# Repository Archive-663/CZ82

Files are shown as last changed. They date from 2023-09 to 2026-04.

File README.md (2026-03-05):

# Lot no. 008 | Grips, Holsters, and Speedloader for the CZ82

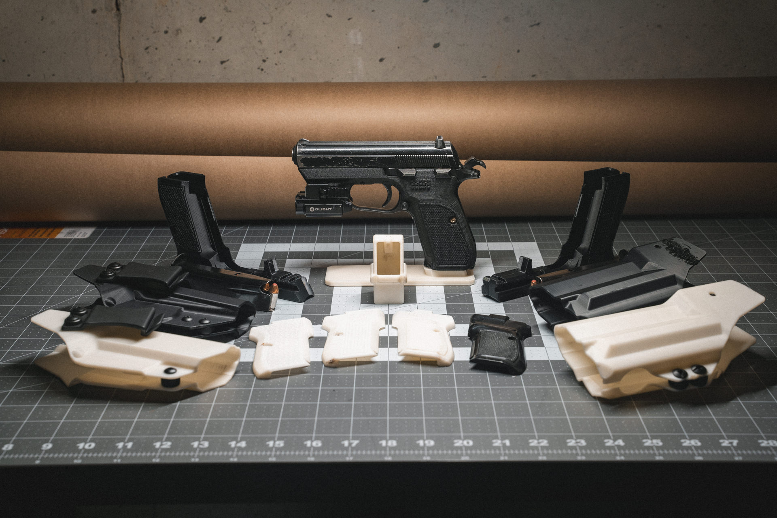
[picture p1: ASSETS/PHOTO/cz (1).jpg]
samplePhoto001


### In this repository:
- [CZ-82 Grips](https://github.com/Archive-663/CZ82/tree/main/Grips)
- [CZ-82 Holsters](https://github.com/Archive-663/CZ82/tree/main/Holsters)
- [CZ-82 +2 Magazine Extension](https://github.com/Archive-663/CZ82/tree/main/Magazine%20Base%20Plate)
- [CZ-82 Speedloader/unloader](https://github.com/Archive-663/CZ82/tree/main/Speedloader)
- [CZ-82 Reverse Engineered Frame & Magazine Assembly in STEP](https://github.com/Archive-663/CZ82/tree/main/baseCZ82_Body)
- [Small Collection of compact weapon lights](https://github.com/Archive-663/CZ82/tree/main/Lights)

### Background Story:
I wanted to carry my CZ-82 with a light, but there weren't any options for me to make this happen. Four years ago I started 3D printing and designing in CAD for photography related things. About two years ago I tried to design a NATO grip for the 82 but didn't like the accuracy of the design as well as the fit. Earlier this year I picked up a 3D scanner that allowed me to better design a fitted NATO grip by helping me reverse engineer the frame and slide. The included CZ82 Frame Assembly STEP file is my best approximation at what CZ designers were thinking back in the 80's. With time and tooling wear through batches there may be some inconsistencies in my file, but it's a good starting point to fit your own grips on your 82/83.

It was a frustratingly hard thing to wrap my head around. It took me about four start ups to finally start understanding how I should be thinking when reverse engineering a made product. There was a lot of guessing at what the 'designer intent' was when making measurements and curves. It was a good learning experience and I believe the finished file is a very good digital approximation of the CZ-82 frame.

### Help support Archive 663 with a dontation or monthly sub



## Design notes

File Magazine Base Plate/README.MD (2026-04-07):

# CZ-82 Plus 2 Magazine Extension

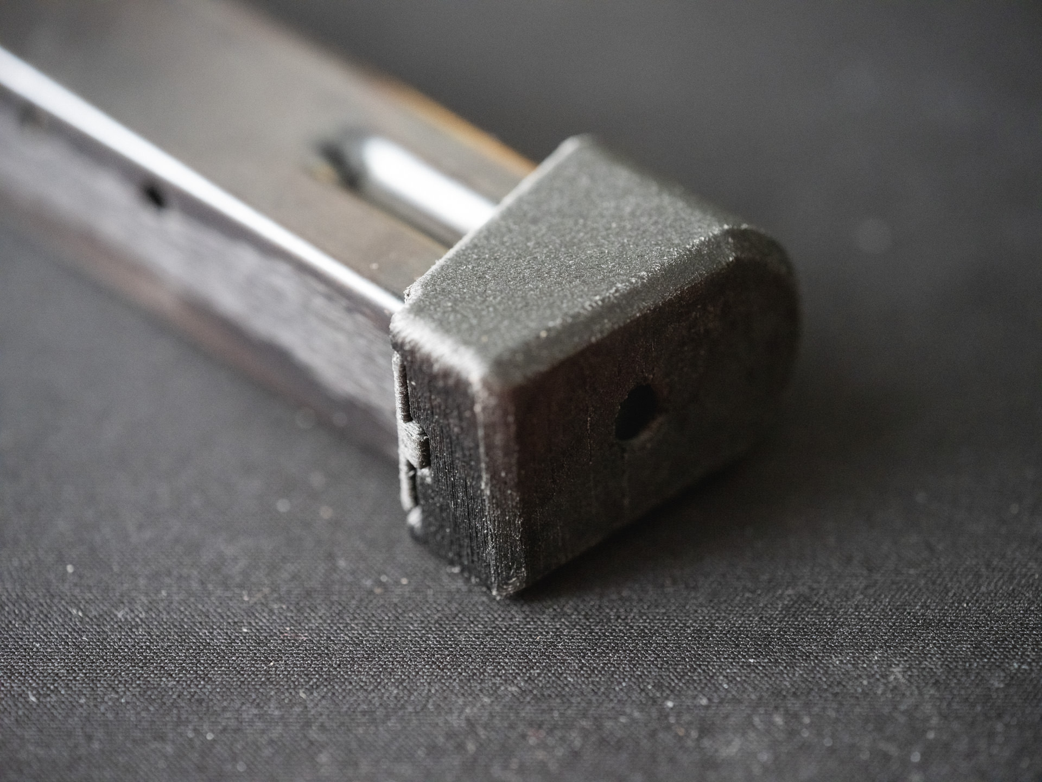
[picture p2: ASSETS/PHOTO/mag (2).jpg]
CZ-82 Plus 2 Magazine Extension 1

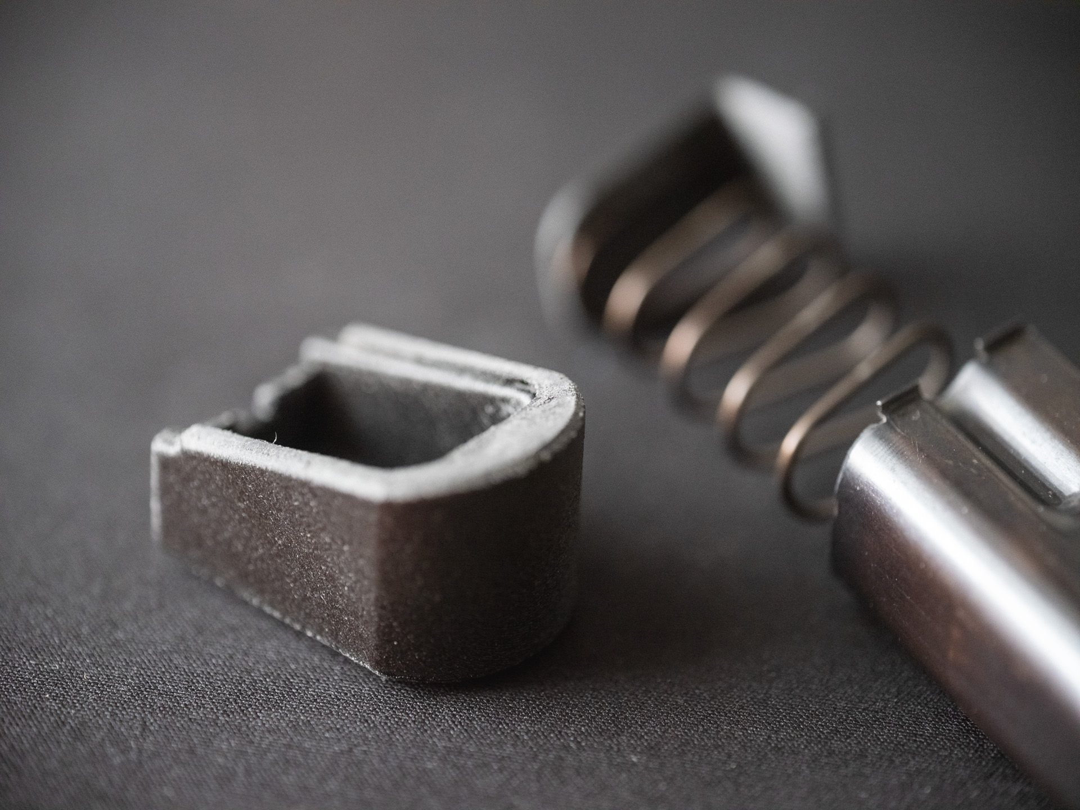
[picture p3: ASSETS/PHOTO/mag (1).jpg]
CZ-82 Plus 2 Magazine Extension 2


A working +2 round magazine extension.

### Features:
- +2 Magazine capacity
- Compatible with Type 1 (Round) and Type 2 (Square) Main Spring Plug

### What you'll need:
- A set of diamond micro files (0.25mm, 0.5mm, 0.75mm)
or 
- A clean sharp edge

### Assembly:
Remove the factory spring retention plate and slide the last spring loop into the printed spring retention plate. Compress the spring and spring retention plate. Slide the +2 magazine base plate on. Allow the spring to decompress, push down on the spring retention plate if it does not drop down.

You want to slide the +2 magazine base plate on without the spring and spring retention plate to ensure that the kerf allows the +2 base plate to slide on without too much issue. It's printed and designed tight to allow for the most material on the upper lip of the kerf.

### Printing suggestion:
- PA6-CF filament offers the best performance.
- If you have the round cylindrical (Type 1) Main Spring Plug print "..._springRetainer_+2.stl"
- If you have the square (Type 2) Main Spring Plug pring "..._springRetainerType2_+2.stl"

### Post Processing:
- Clean any stray filament.
- If possible run a .75mm file through the rim of the +2 magazine base plate to ready it for sliding onto the magazine.

### Help support Archive 663 with a dontation or monthly sub



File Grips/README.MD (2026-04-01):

# CZ-82 Grips

CZ-82 Speedloader
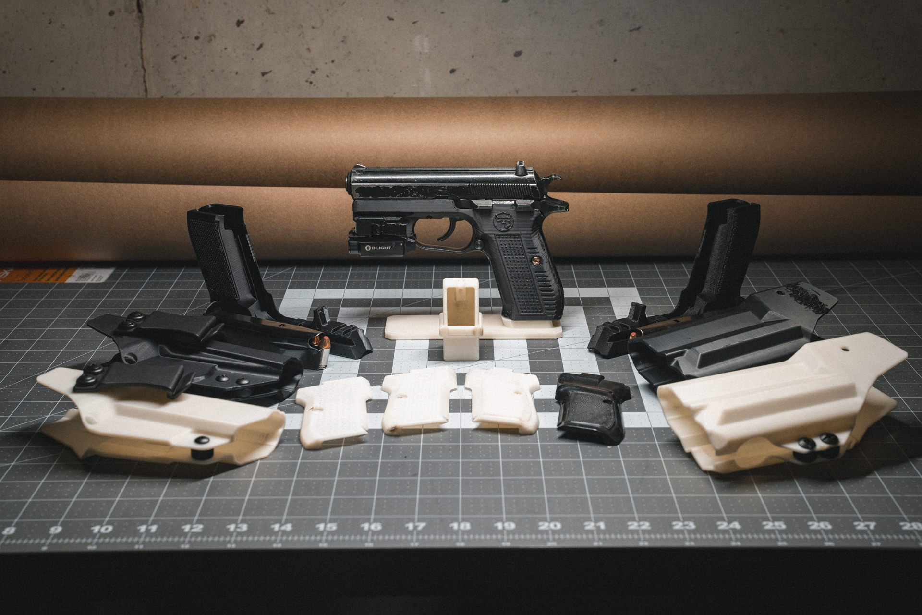
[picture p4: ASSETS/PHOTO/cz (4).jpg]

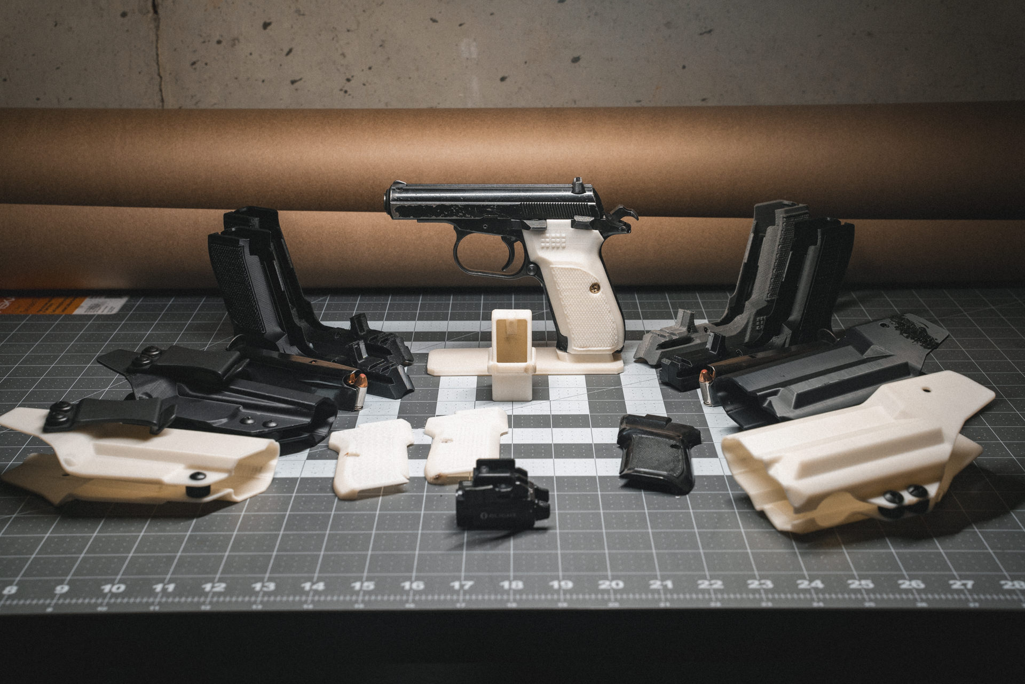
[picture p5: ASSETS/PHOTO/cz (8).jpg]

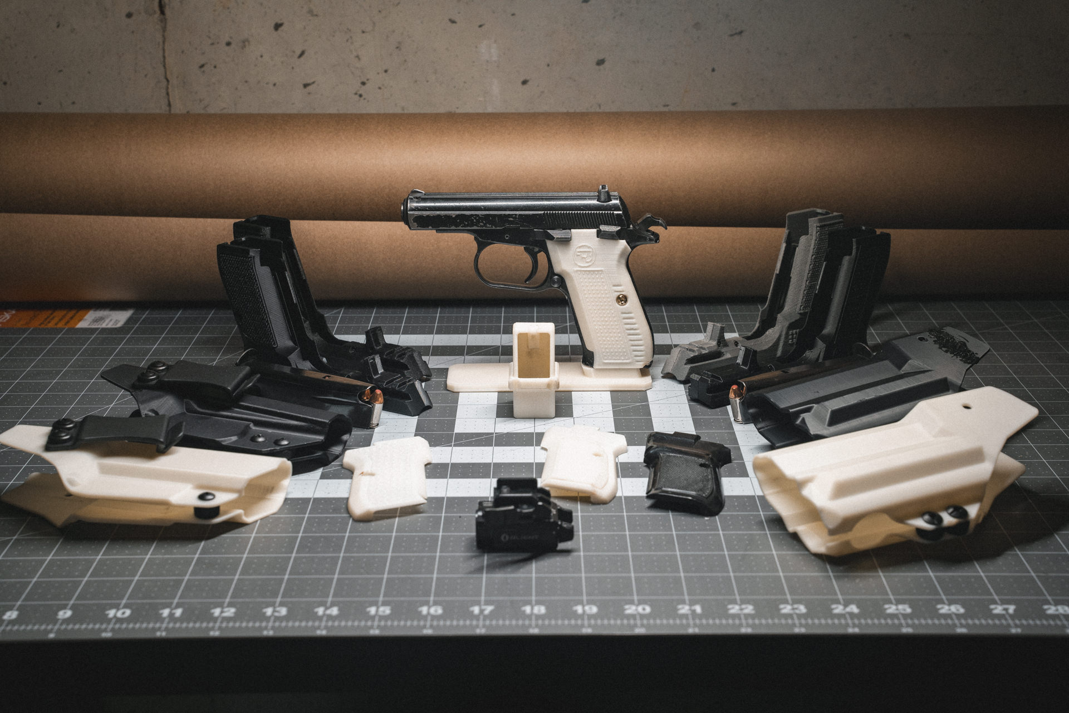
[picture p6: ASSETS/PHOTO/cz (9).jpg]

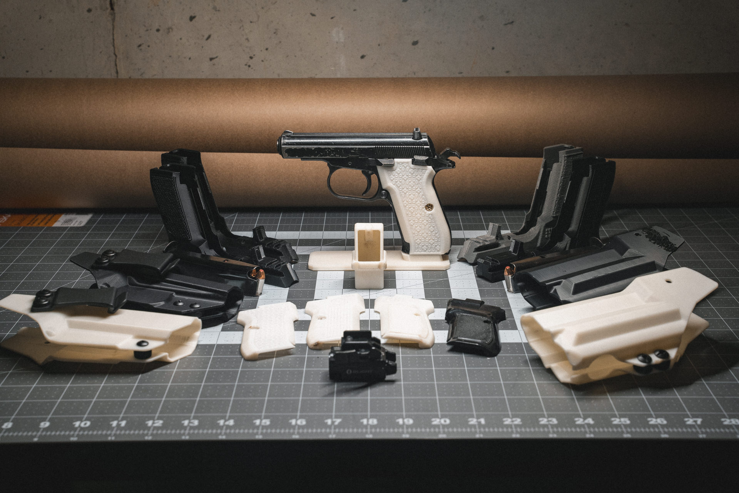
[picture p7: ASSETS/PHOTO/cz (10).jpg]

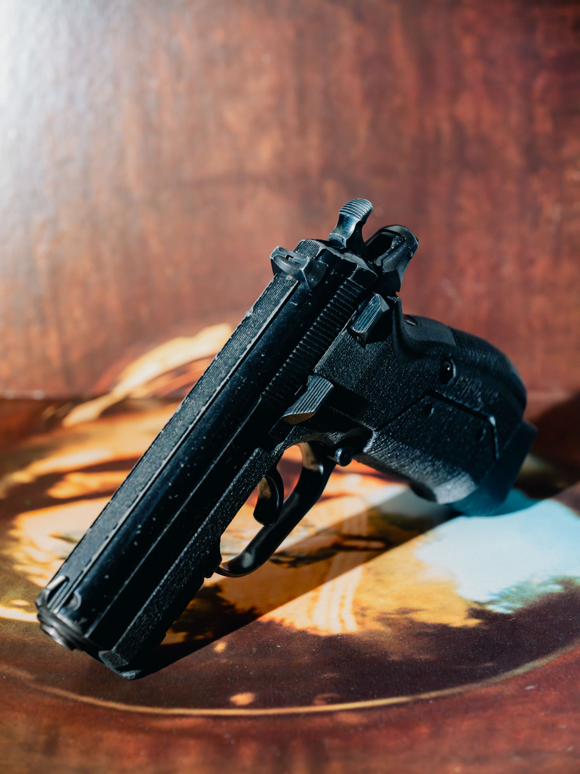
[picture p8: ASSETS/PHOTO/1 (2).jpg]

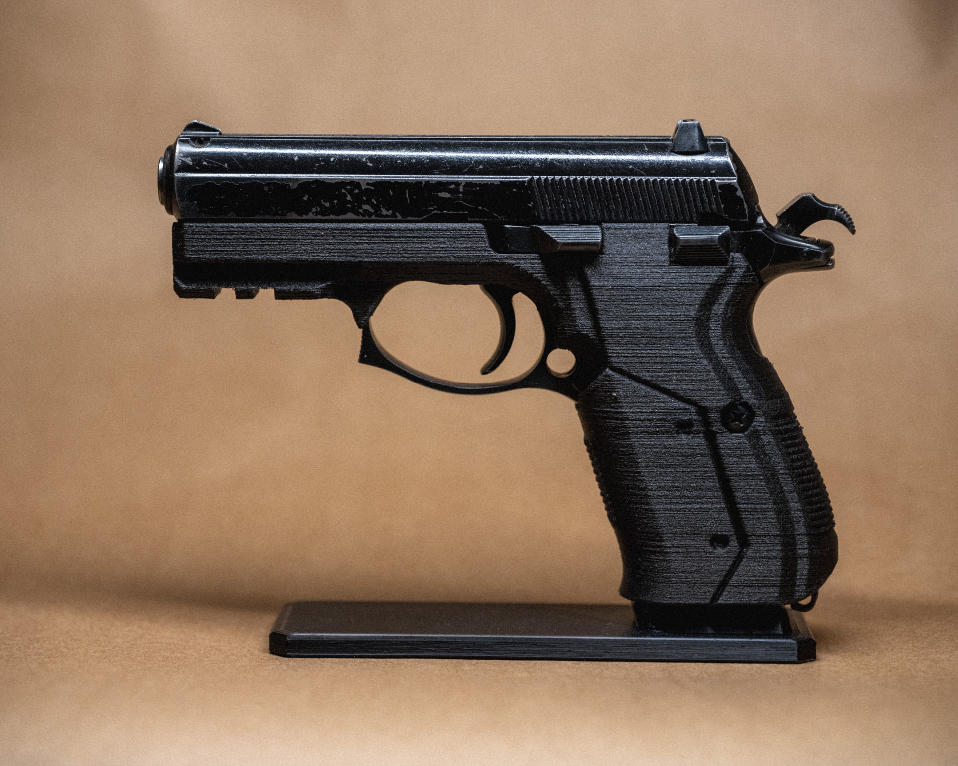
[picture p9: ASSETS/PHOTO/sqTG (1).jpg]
CZ-82 nato checkered sqTG


A collection of Grips to improve the handling for the CZ-82 and CZ-83 (w/o square trigger guard)

### Features:
- NATO compliant rail (compatible with 1913 rail attachments as well)
- Aggressive checkering on 34mm grips
- CZ Retro style 28mm grips
- Cowboy Bebop inspired "wrap around" grips
- Simplified ethnic 'Elephant's Foot Pattern' style 28mm grips
- Standard 34mm grips and Slim 28mm grips

### What you'll need:
- 2x M2 x 14mm Hex Cap Screws
- 1x M2 x 10mm Hex Cap Screw
- 1x M2 x 8mm Hex Cap Screw
- 4x M2 Nuts
- 2x CZ-82 Grip Screws or CZ-75 Slim Grip Screws
- M2 Drill Bit
- M3.5 Drill Bit

### Printing suggestion:
- FOR NATO GRIPS: PA6-GF filament would be the best balance in ease of printing and durability. Second choice would be ABS for it's ease of printing, relatively good detail, and strength. Do not use PETG or any other brittle/prone to shatter on impact filament.
- FOR Standard Grips: ABS was perfectly fine for me. While the grips still have to deal with the impact shock from the recoil it's felt less.
- No resin printing; too britle. 
- Follow the printOrientationFile.3mf for print orientation. If importing to CURA you can simply import the models and then slice with your settings. In PrusaSlicer it does not carry the information over well from CURA.
- For NATO Grips best detail to strength ratio, print at a -135 degree angle. Details facing the bed. Essentially upsidedown at a 45 degree angle. Check the printOrientationFile.3mf for a visual example. Additionally, you want to sink your print -1.5mm on the Z-axis so your printer has a foot to print the grips. Make sure you have good adhesion.
- For the Standard Grips best detail to strength ratio, print at a 45 degree angle. Details facing the bed. Check the printOrientationFile.3mf for a visual example. Additionally, you want to sink your print -0.5mm on the Z-axis so your printer has a foot to print the grips. Make sure you have good adhesion.

### Post Processing:
- Drill out the M2 and M3.5 holes.
- Using an M2 x 14mm screw, press fit the M2 nuts on the Right NATO Grip.
- Not much post processing is needed if you're printing with ABS besides support removal and clean up on parts of the texture. 
- If you're printing with PA6-GF you need to anneal the print. My method is 30 minutes to 1 hour in 70C water using a sous vide to keep temp. If you want to dye to Black or Forest Green add RIT Dye to the water to anneal and dye. There will be a fair bit of clean up on whiskers as PA6-GF, for me, was stringy. Use a sharp razor blade or exacto to clean up any errant hairs. 

### Designing your own grips:
I've included a base Left sided grip. It has the correct internal geometries while leaving the exterior untouched. It's a good starting point if you want to custom fit a grip style to fit your hand. If you want to modify the NATO grips included the import the STEP files to what ever CAD system you're using. 

### Help support Archive 663 with a dontation or monthly sub



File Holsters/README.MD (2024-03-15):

# CZ-82 Holsters

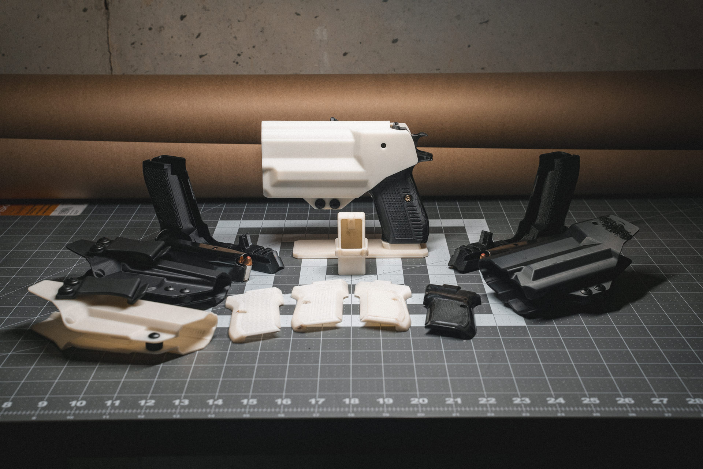
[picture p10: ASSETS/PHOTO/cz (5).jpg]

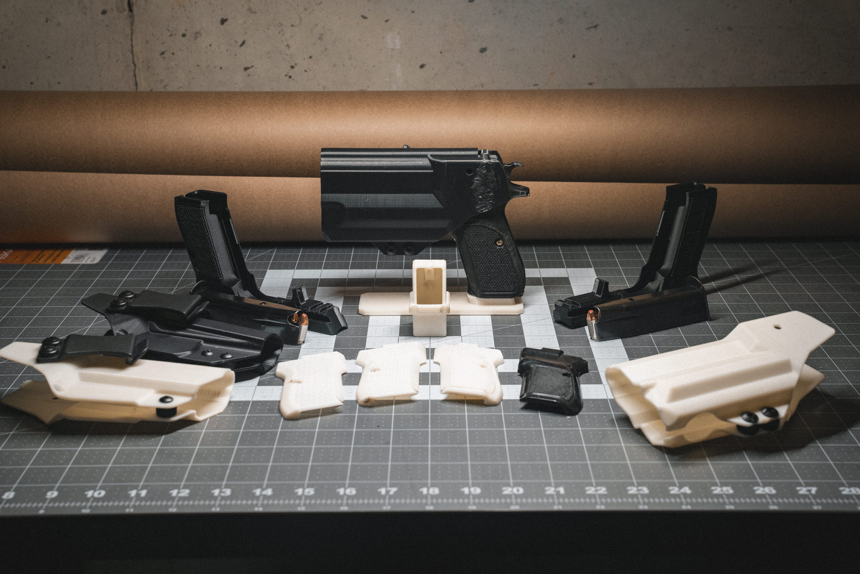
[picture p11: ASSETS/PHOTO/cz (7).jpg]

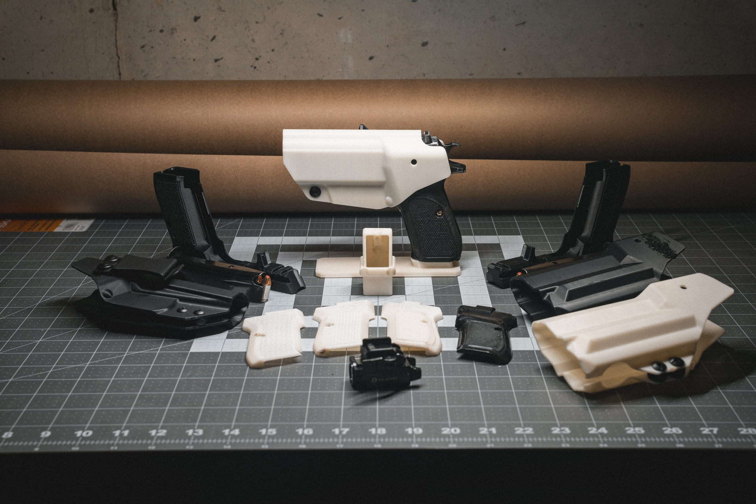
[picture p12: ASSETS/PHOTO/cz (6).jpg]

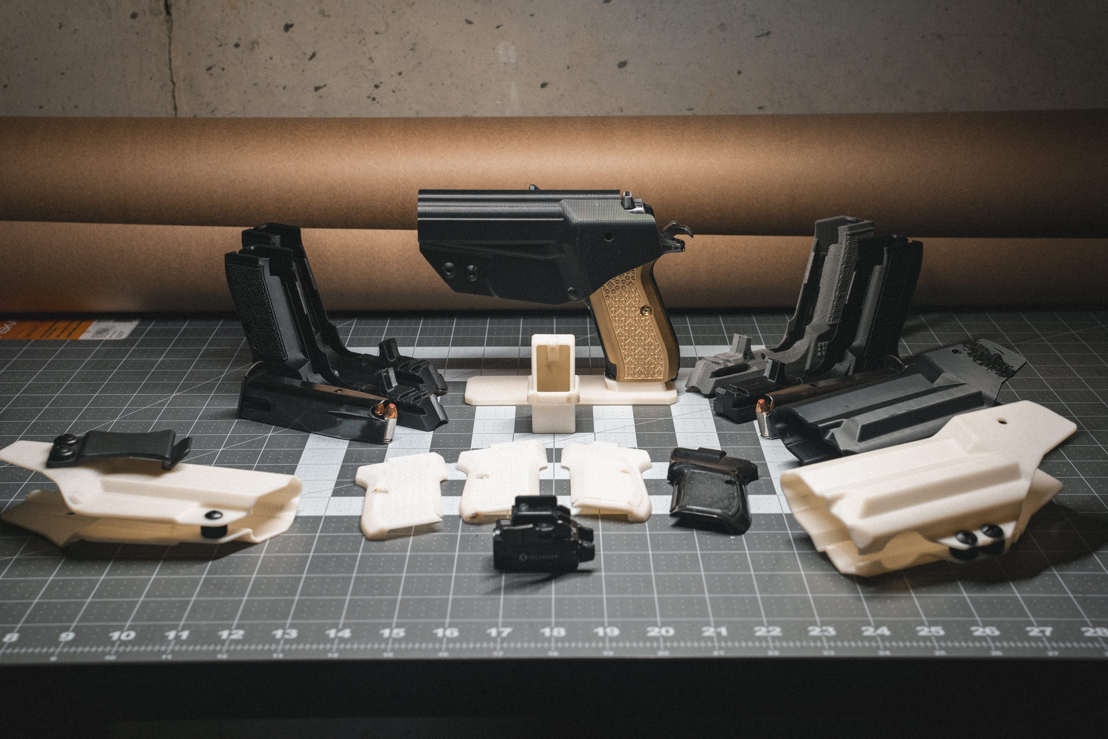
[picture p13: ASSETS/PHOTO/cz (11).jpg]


A collection of holsters for the CZ-82 and CZ-83 (w/o square trigger guard)

### Features:
- Ambidextrous belt mount
- 15mm bushing spacing for most claw attachments

### What you'll need:
- 2x 3/8 holster bushings w/hardware
- 1x belt loop w/hardware

### Printing suggestion:
- ABS filament would be the best balance in ease of printing and durability. Not as resistant to solvents as PETG but better impact resistance and elongation before breakage. Better heat and UV resistance than PLA.
- Follow the printOrientationFile.3mf for print orientation. If importing to CURA you can simply import the models and then slice with your settings. In PrusaSlicer it does not carry the information over well from CURA.

### Post Processing:
- You will need to <a href='https://www.cnckitchen.com/blog/testing-the-strength-of-3d-prints-re-melted-in-salt' target='_blank'>salt re-flow</a> your prints for maximum strength. Either that or simply weld the layers with a soldering iron where your mounting points are. You will have to drill out holes to fit your mounting hardware and your cant angle.

### Additional Notes:
If you want a "Kydex" style version, you can use the included STEP files for the holsters to create your "buck" for vacuum forming the holster. What you'll need to do is subtract the holster from a rectangle in CAD, split the subtracted body, add breather channels and holes at corners, cut or print your buck, and then vacuum form your preferred thermoplastic sheet.

### Help support Archive 663 with a dontation or monthly sub



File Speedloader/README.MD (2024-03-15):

# CZ-82 9x18mm Speedloader/unloader

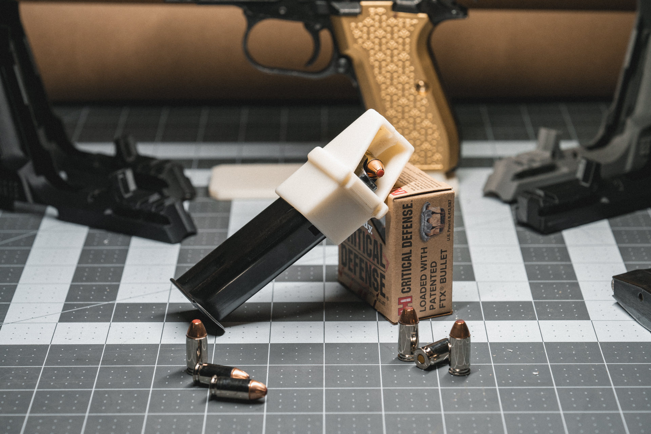
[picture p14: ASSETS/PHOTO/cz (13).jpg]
CZ-82 Speedloader


An optimized speedloader and unloader for CZ-82 & CZ-83 magazines

### Features:
- Ambidextrous unloading tabs
- Replaceable plunger
- Compact size

### Printing suggestion:
- ABS filament would be the best balance in ease of printing and durability. Not as resistant to solvents as PETG but better impact resistance and elongation before breakage. Better heat and UV resistance than PLA.
- Follow the printOrientationFile.3mf for print orientation. If importing to CURA you can simply import the models and then slice with your settings. In PrusaSlicer it does not carry the information over well from CURA.

### Post Processing:
- You may need to file the dovetail for the plunger to fit snuggly. If your support settings are setup well, there shouldn't be much more in post than the filing.

### Help support Archive 663 with a dontation or monthly sub



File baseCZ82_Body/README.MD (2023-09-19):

# baseCZ82_Body Readme

### CZ82_basebody.stp

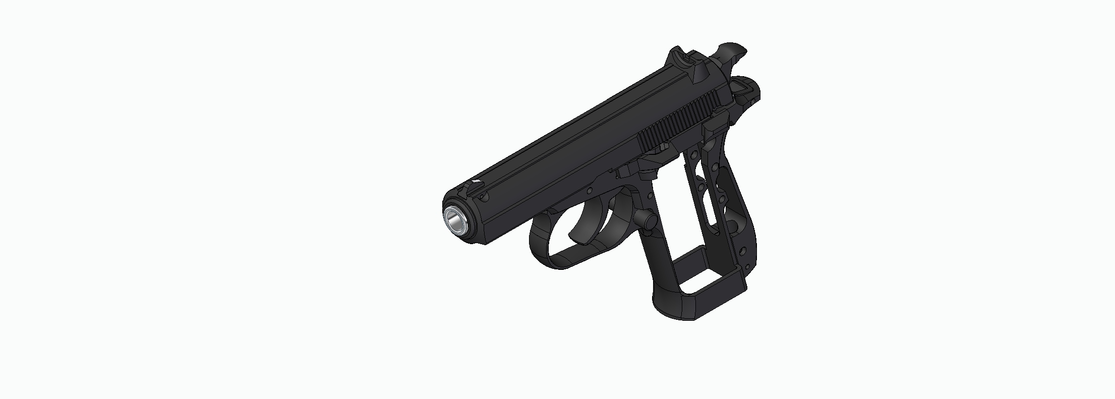
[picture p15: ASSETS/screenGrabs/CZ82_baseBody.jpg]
CZ82_baseBody image


This file contains multiple parts in an assembly. When you open the file it should have everything where it needs to be so you can design around it. I scanned my personal '88 CZ-82 so there may be differences between frames because of tooling differences between batches. Created in Solid Edge 2021. Confirmed working in FreeCAD.

### CZ82_baseMagazine.stp

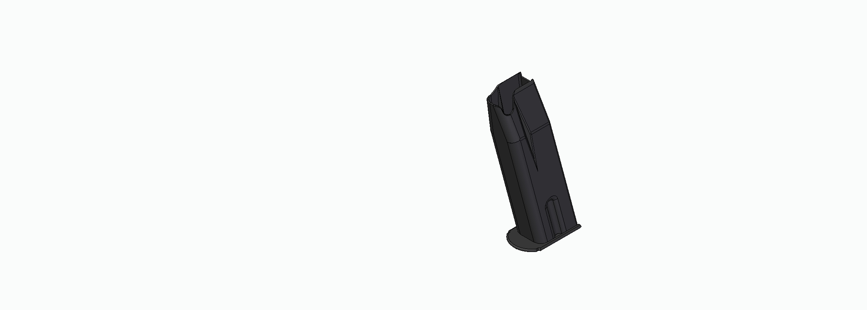
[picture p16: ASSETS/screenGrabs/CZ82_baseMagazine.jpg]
CZ82_baseMagazine image


This file contains multiple parts in an assembly. When you open the file it should have everything where it needs to be so you can design around it. It was built using calipers and physical measurements from an 'x' marked magazine along with a few infered design elements and interpreted designer intent. Created in Solid Edge 2021. Confirmed working in FreeCAD.

### Help support Archive 663 with a dontation or monthly sub



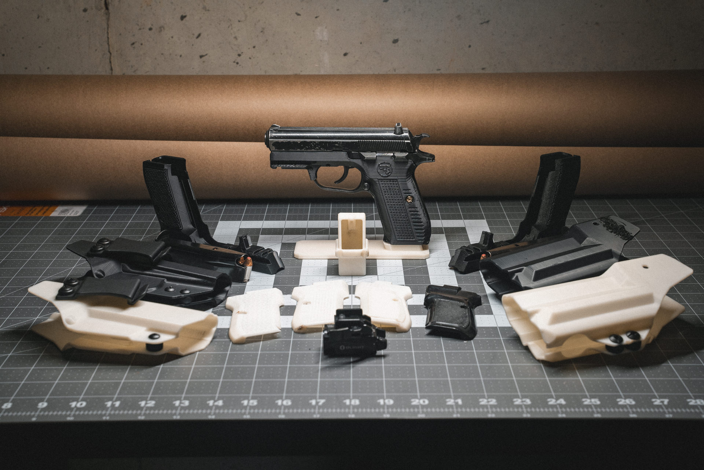
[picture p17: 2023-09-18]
ASSETS/PHOTO/cz (3).jpg

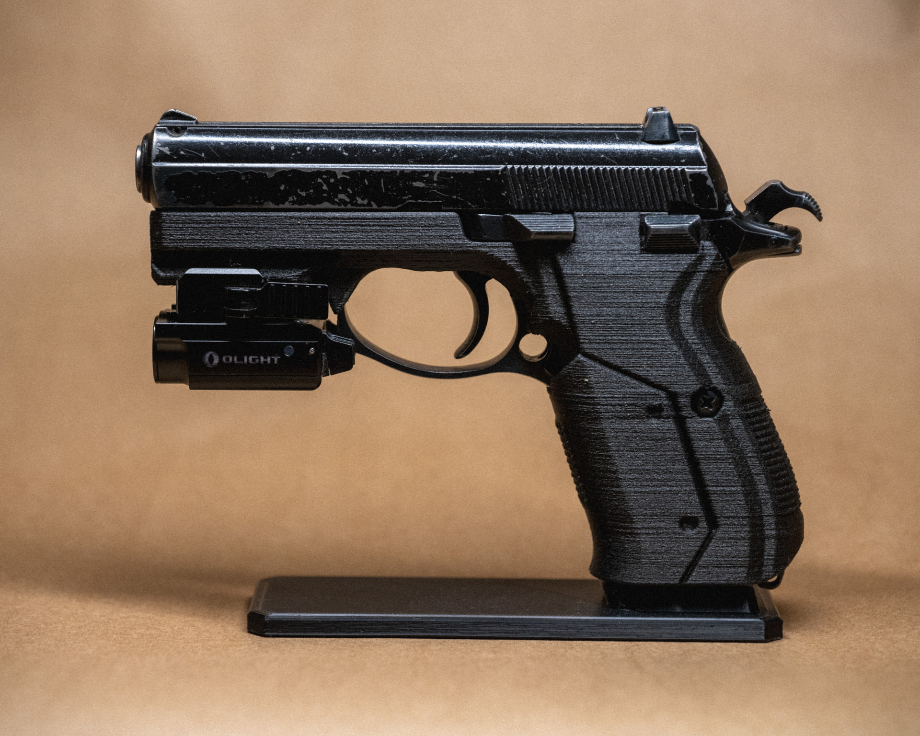
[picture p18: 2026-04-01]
ASSETS/PHOTO/sqTG (3).jpg

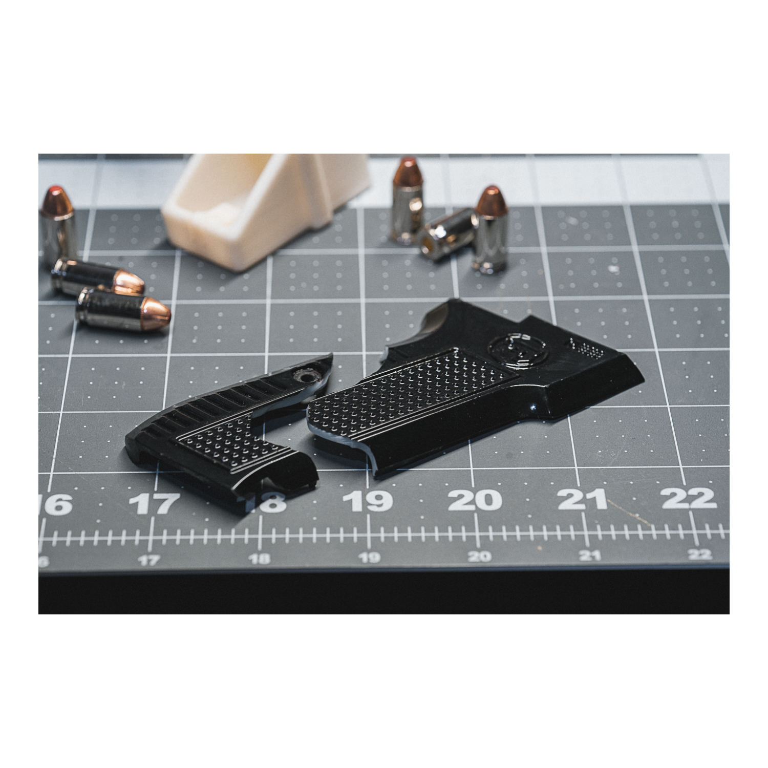
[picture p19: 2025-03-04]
ASSETS/PHOTO/INSTA/INSTA-18.jpg

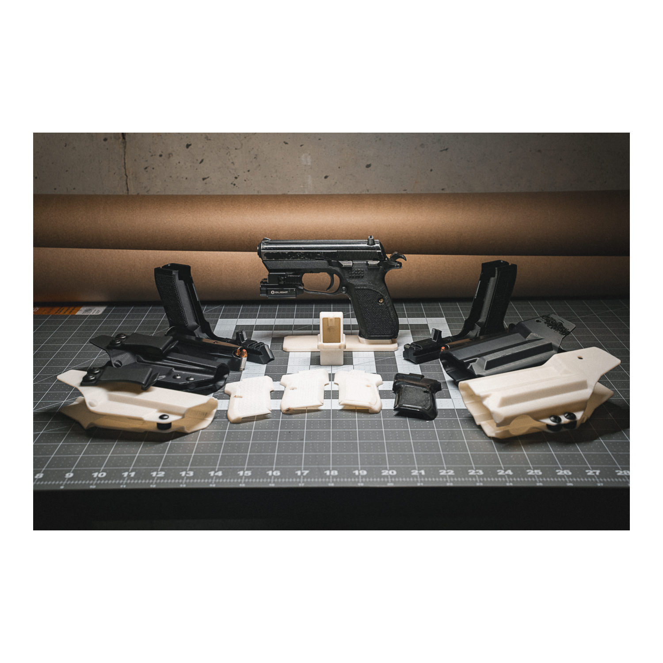
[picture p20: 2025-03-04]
ASSETS/PHOTO/INSTA/INSTA-02.jpg

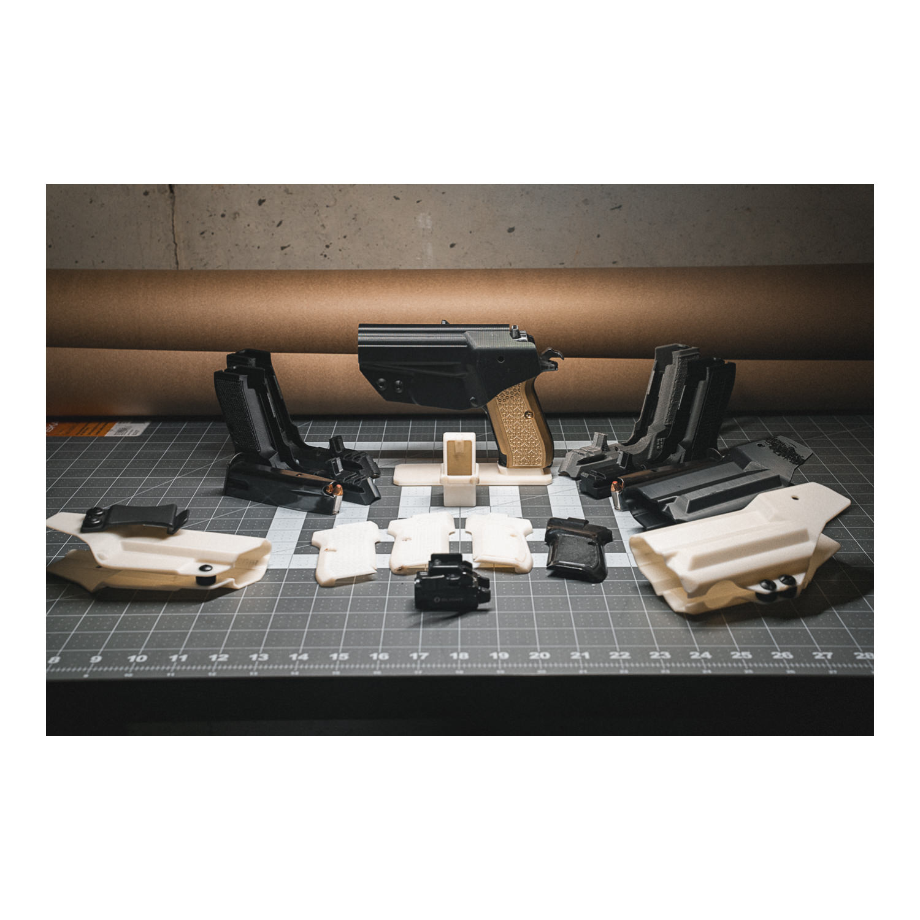
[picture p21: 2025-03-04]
ASSETS/PHOTO/INSTA/INSTA-14.jpg

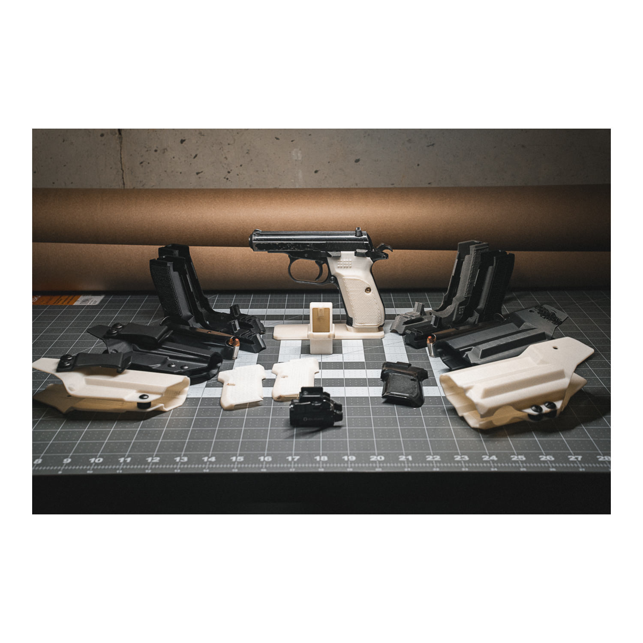
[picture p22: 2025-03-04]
ASSETS/PHOTO/INSTA/INSTA-11.jpg

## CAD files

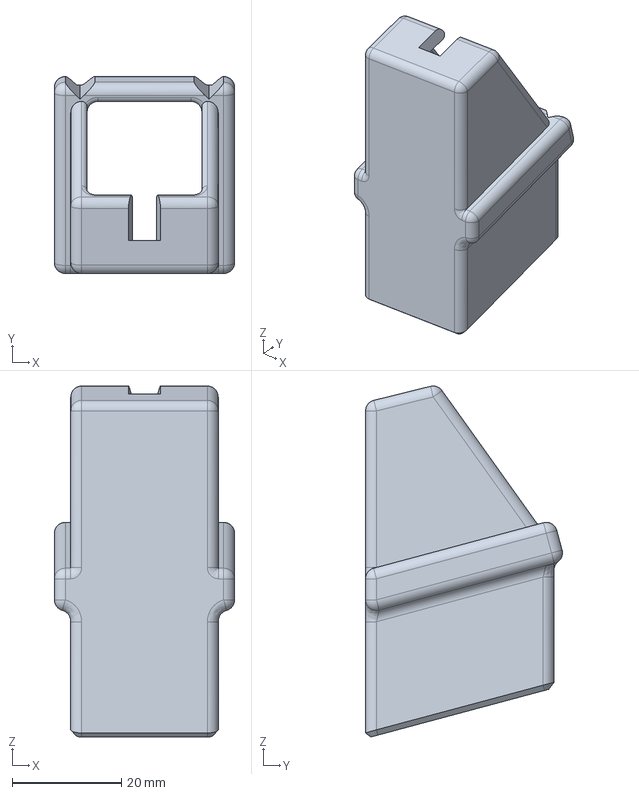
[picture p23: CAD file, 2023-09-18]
Speedloader/STEP/CZ82_speedLoader_mainBody.stp
33.0 x 36.1 x 64.2 mm

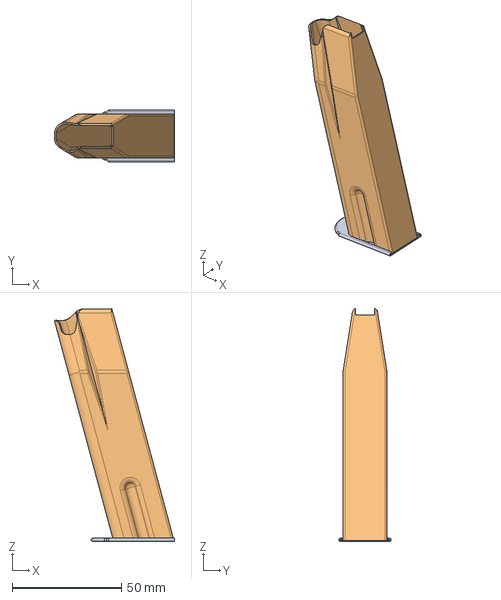
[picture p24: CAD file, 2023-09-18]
baseCZ82_Body/CZ82_baseMagazine.stp
55.1 x 24.0 x 106.8 mm
CZ82_baseMagazinePlate
CZ82_baseMagazine

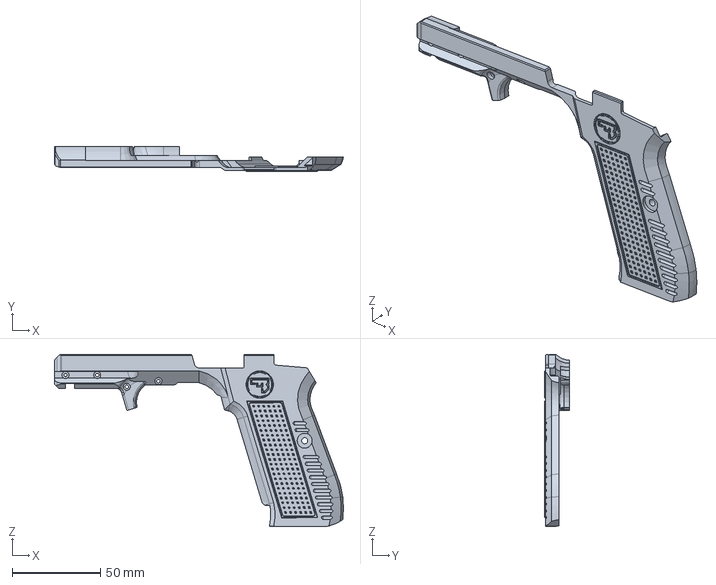
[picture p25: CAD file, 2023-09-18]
Grips/STEP/CZ82_standardGripLeft_NATO_slim.stp
164.0 x 14.2 x 97.7 mm

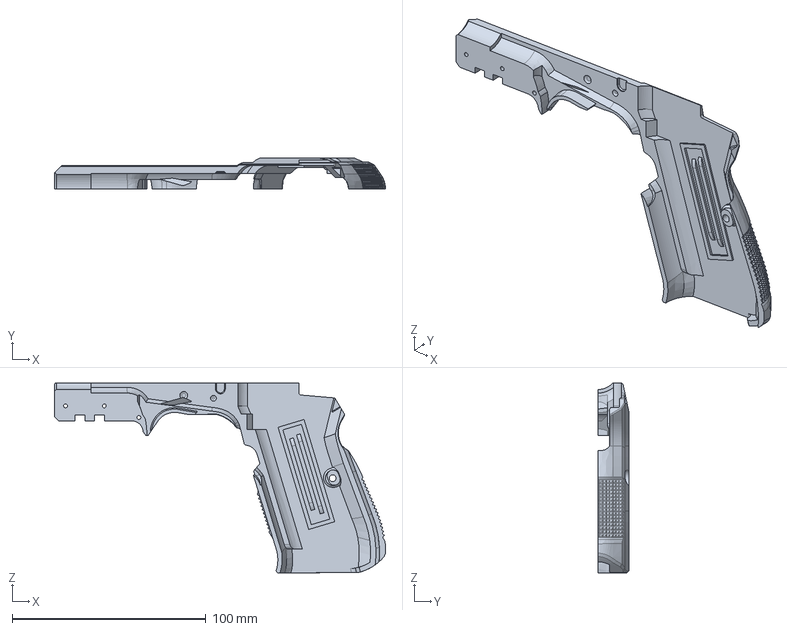
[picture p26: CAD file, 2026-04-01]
Grips/STEP/NATO_Bebop/CZ82_standardGripRight_NATO_bebop_checkering_squareTGa.stp
170.7 x 16.0 x 97.8 mm

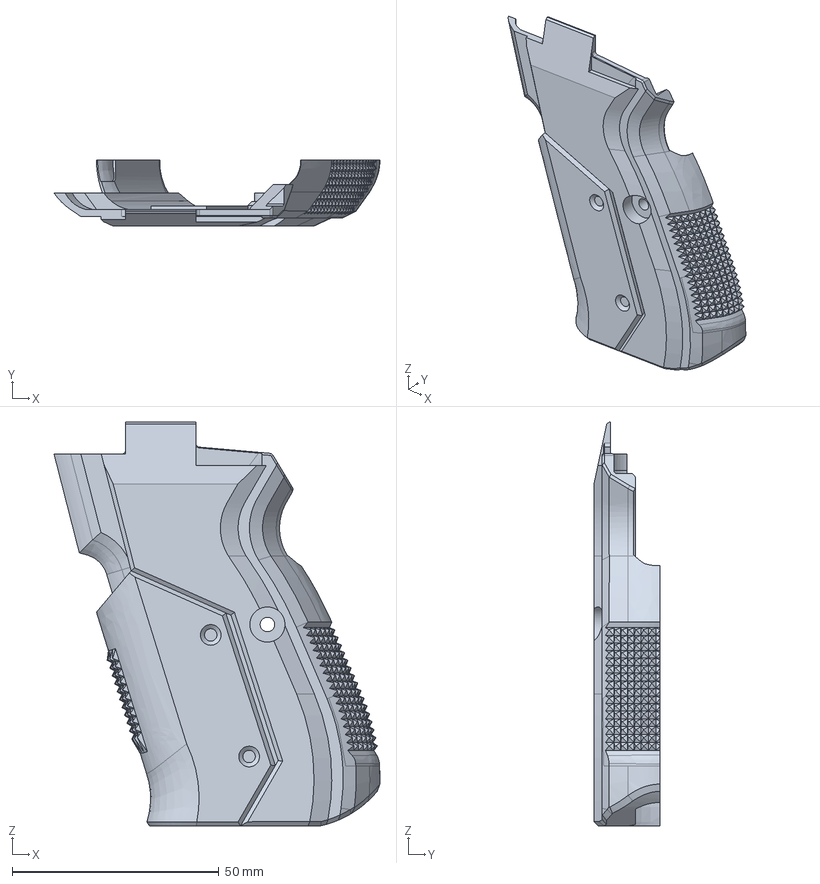
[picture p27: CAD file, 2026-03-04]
Grips/STEP/Slim_Bebop/CZ82_standardGripLeft_Slim_bebop_checkering.stp
78.9 x 16.0 x 97.7 mm

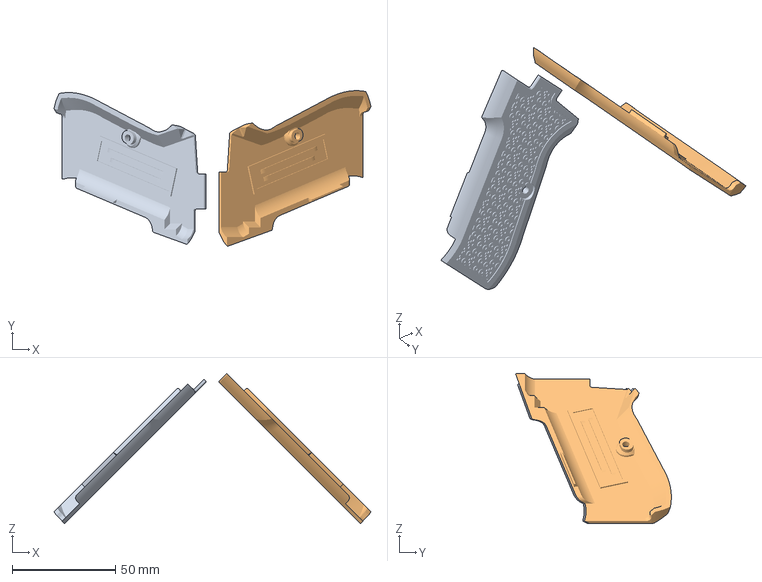
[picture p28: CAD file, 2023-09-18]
Grips/STL/Slim_28mm/Elephants Foot Pattern Grip/CZ82_standardGripLeft_28mm_printOrientationFile.3mf
153.5 x 75.4 x 72.8 mm
CZ82_standardGripLeft_28mm.stl
CZ82_standardGripRight_28mm.stl

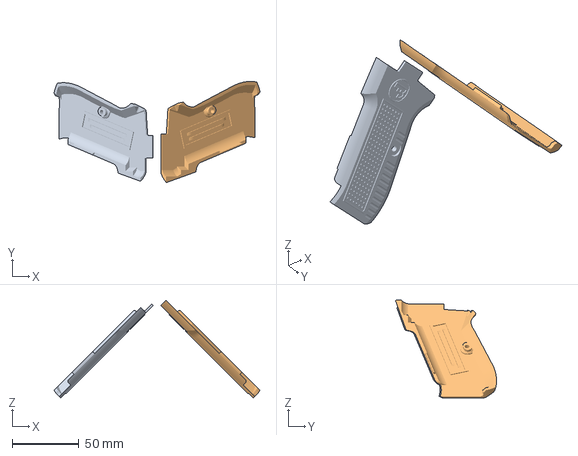
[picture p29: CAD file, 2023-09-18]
Grips/STL/Slim_28mm/RETRO Grip/CZ82_standardGripLeft_Retro_28mm_printOrientationFile.3mf
153.9 x 75.5 x 73.1 mm
CZ82_standardGripLeft_Retro_28mm.stl
CZ82_standardGripRight_Retro_28mm.stl

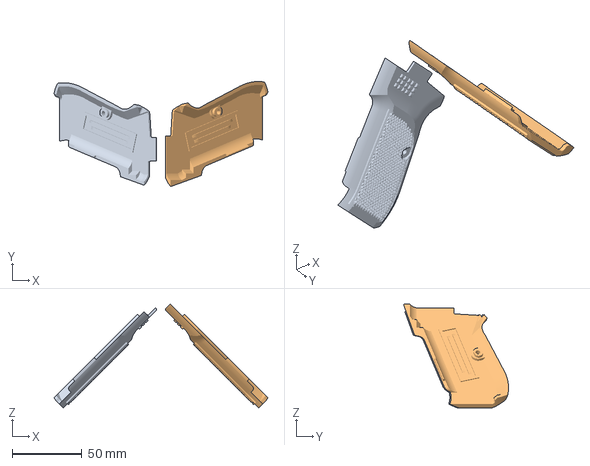
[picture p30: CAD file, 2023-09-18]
Grips/STL/Standard_34mm/CZ82_standardGripLeft_34mm_printOrientationFile.3mf
153.9 x 75.5 x 74.8 mm
CZ82_standardGripLeft_34mm.stl
CZ82_standardGripRight_34mm.stl

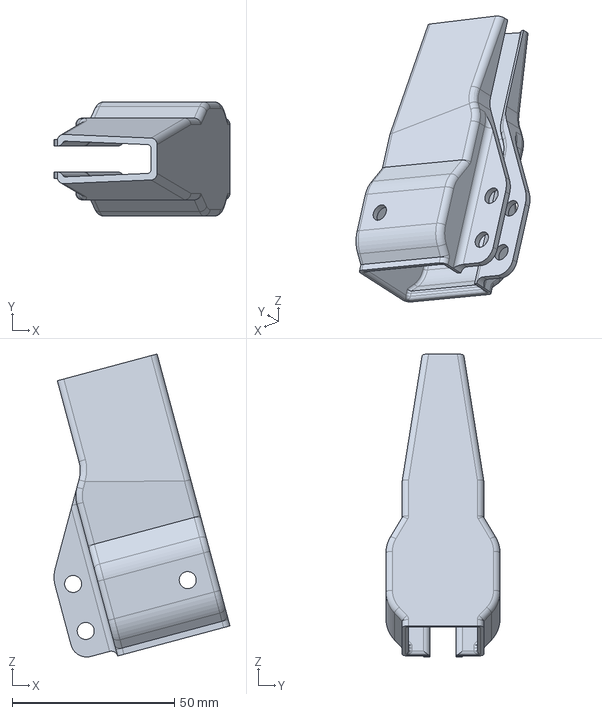
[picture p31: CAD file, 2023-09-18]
Holsters/STEP/CZ82_baseMagazineHolster.stp
54.2 x 35.2 x 93.4 mm

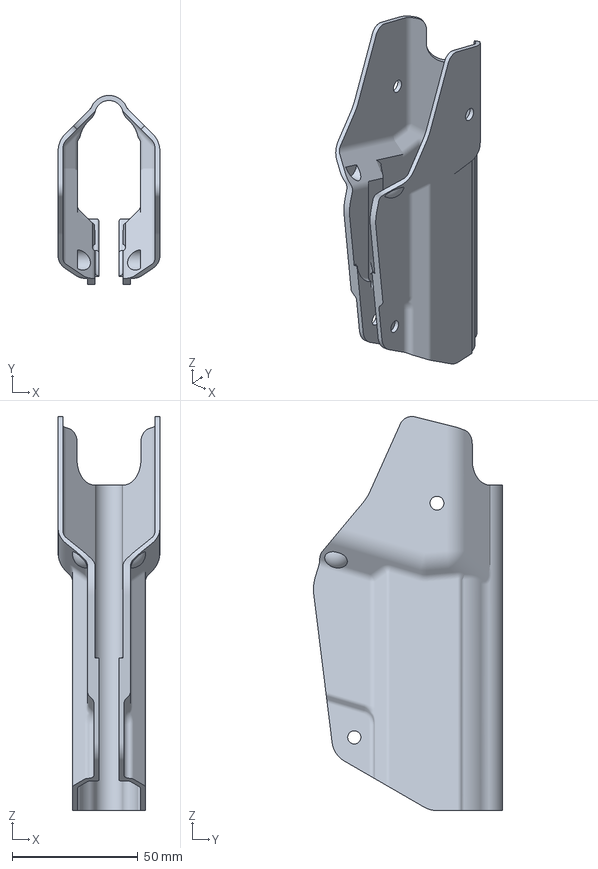
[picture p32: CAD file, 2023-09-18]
Holsters/STL/CZ82_baseNoLightNATOHolster_printOrientationFile.3mf
40.5 x 75.2 x 156.8 mm

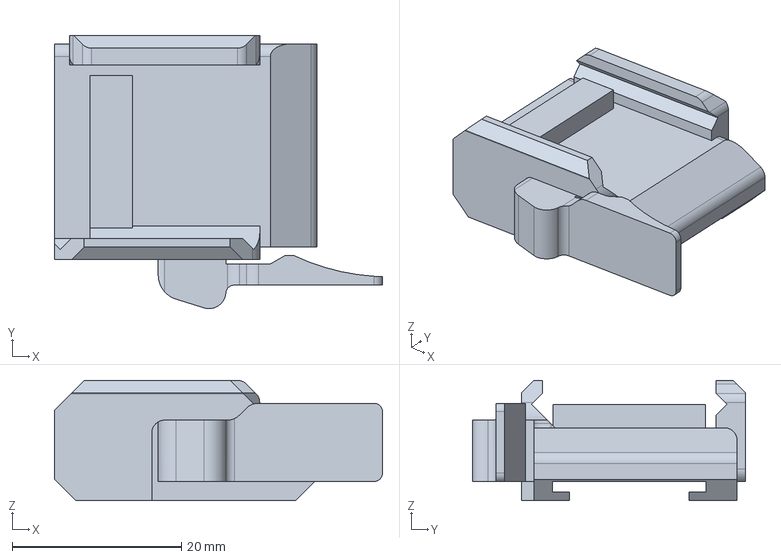
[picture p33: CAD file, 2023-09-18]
Lights/STEP/olight_PL_MINI2/oLight_PL_MINI2.stp
38.8 x 32.3 x 14.2 mm

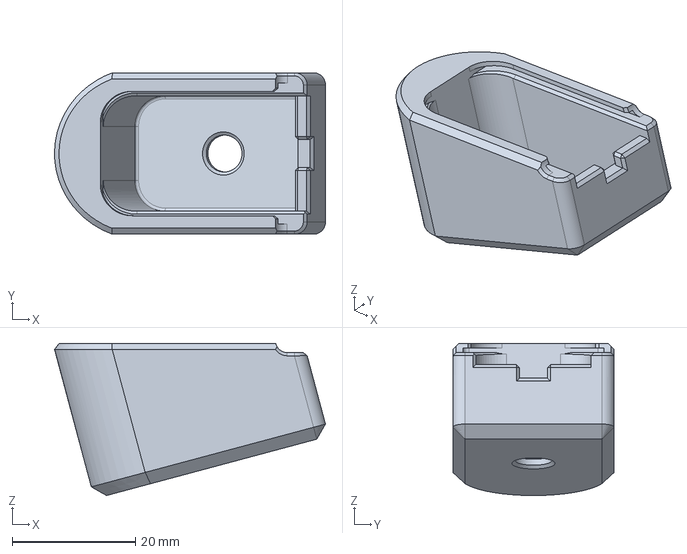
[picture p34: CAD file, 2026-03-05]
Magazine Base Plate/STEP/CZ82_magazineExtension_+2.stp
44.0 x 26.2 x 24.7 mm

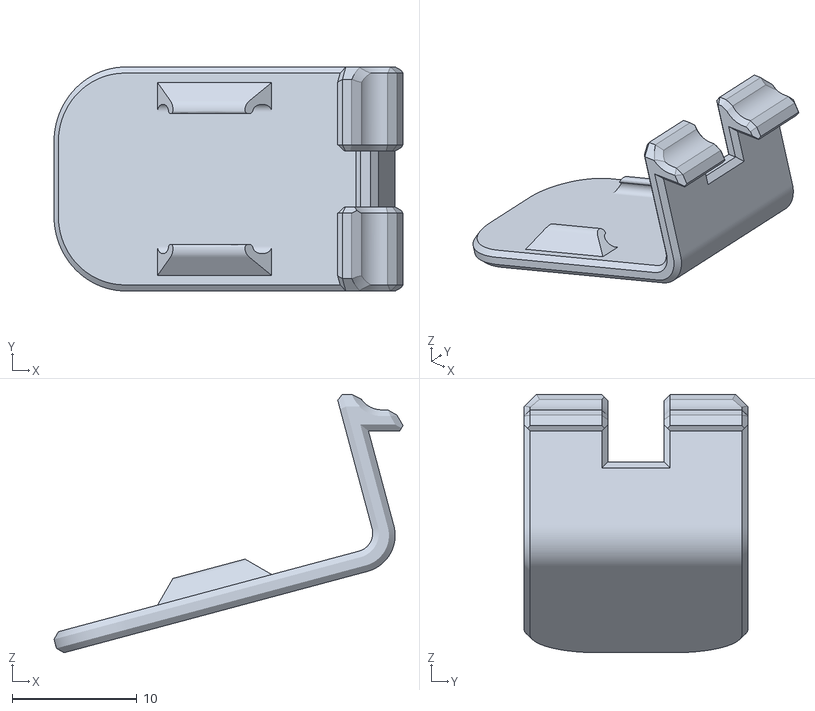
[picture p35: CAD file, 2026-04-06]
Magazine Base Plate/STL/CZ82_magazineExtension_springRetainerType2_+2.stl
28.0 x 18.0 x 20.8

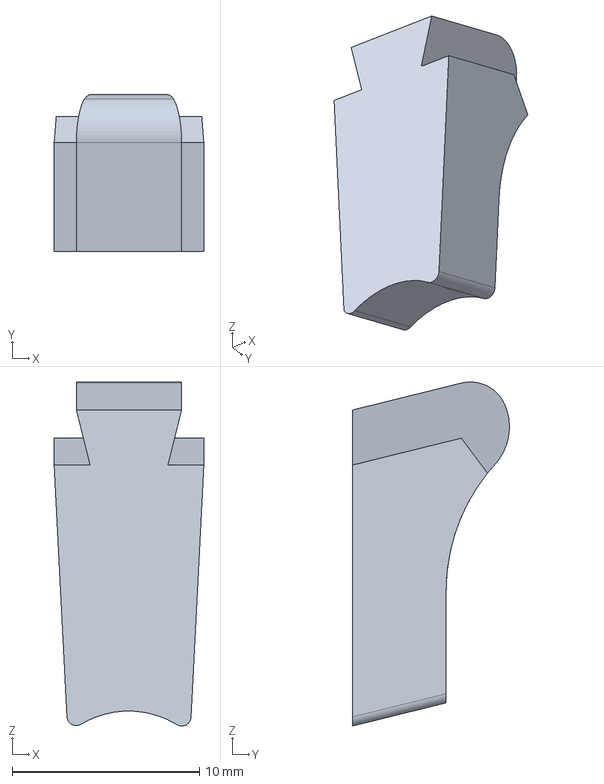
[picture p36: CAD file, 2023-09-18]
Speedloader/STEP/CZ82_speedLoader_plunger.stp
8.00 x 8.38 x 18.4 mm

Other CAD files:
Speedloader/STL/CZ82_speedLoader_printOrientationFile.3mf
baseCZ82_Body/CZ82_baseBody.stp
Grips/STEP/CZ82_standardGripRight_NATO_slim.stp
Grips/STEP/NATO_Bebop/CZ82_standardGripLeft_NATO_bebop_checkering_squareTGa.stp
Grips/STEP/CZ82_standardGripLeft_28mm.stp
Grips/STEP/CZ82_standardGripLeft_Base.stp
Grips/STEP/CZ82_standardGripLeft_Retro_28mm.stp
Grips/STEP/CZ82_standardGripRight_28mm.stp
Grips/STEP/CZ82_standardGripRight_Retro_28mm.stp
Grips/STEP/NATO_Bebop/CZ82_standardGripLeft_NATO_bebop.stp
Grips/STEP/NATO_Bebop/CZ82_standardGripLeft_NATO_bebop_checkering.stp
Grips/STEP/NATO_Bebop/CZ82_standardGripRight_NATO_bebop.stp
Grips/STEP/NATO_Bebop/CZ82_standardGripRight_NATO_bebop_checkering.stp
Grips/STEP/Slim_Bebop/CZ82_standardGripLeft_Slim_bebop.stp
Grips/STEP/Slim_Bebop/CZ82_standardGripRight_Slim_bebop.stp
Grips/STEP/Slim_Bebop/CZ82_standardGripRight_Slim_bebop_checkering.stp
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

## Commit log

2023-09-18 Upload STL, Photos
    [CZ82_speedLoader_mainBody.stl, CZ82_speedLoader_plunger.stl, CZ82_standardGripLeft_28mm.stl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]
2023-09-18 Upload STEP + printOrientation
    [CZ82_baseBody.stp, CZ82_baseHolster.stp, CZ82_baseHolster_printOrientationFile.3mf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]
2023-09-18 update photos
    [CZ82_baseMagazine.stp, CZ82_baseMagazineHolster.stp]
